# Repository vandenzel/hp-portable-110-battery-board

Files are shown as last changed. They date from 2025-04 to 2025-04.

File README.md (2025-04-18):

# HP Portable 110 Battery Board

A replacement board to stick onto the battery pack of a HP Portable 110 computer. But with some SMD parts. Also the 3 pin header should be a locking/latching part instead of "just" a pin header.

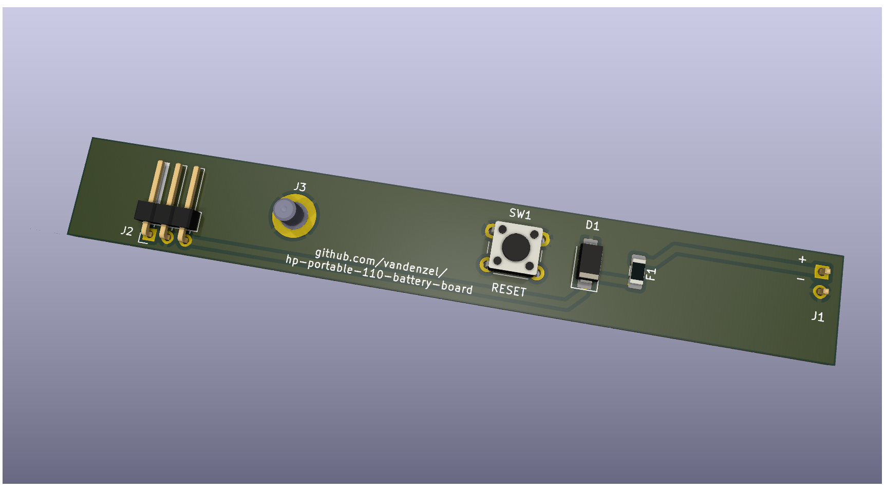
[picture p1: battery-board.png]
PCB render

I didn't have a 3D image for the F1 fuse, or the J3 stud.

## Parts list

On PCB

| Part | Description | Notes |
| ---- | --- | --- |
| D1 | 1N4001 | this should be a D_SMA package |
| F1 | 0.5A | [Mouser](https://mou.sr/42zEMhM) |
| J1 | header 1x2 2.54mm pitch | pinheader, or JST-XH, or wires soldered directly to PCB |
| J2 | header 1x3 2.54mm pitch | plain pinheader or something compatible with the locking connector |
| J3 | screw terminal | Press-fit M3 stud 6mm long ([PEM KFH-M3-6ET at Mouser](https://mou.sr/3RKMalD)) |
| SW1  | Reset switch | Tact switch |

External to PCB

| Part | Description | Notes |
| ---- | --- | --- |
| BT'1 | 6V 2.5Ah Lead Acid battery | i.e. LP 6-2.8 VRLA AGM Battery |
| J'1  | 1x02 2.54 pitch (female) | could be omitted and wires soldered directly to board |

The battery usually has spade connectors, and the amperage is not really high, so basically any wire with a spade (a.k.a AMP) connector can be used. To connect it to the circuit board you can use a pinheader (like in the image), or a (2.54mm pitch) JST-XH connector, or just solder the wire to the respective holes.

If all goes well, the circuit board can be stuck to the battery using a piece of double sided, foam core sticky tape. Foam core to allow for the through-hole pins. Before sticking it on, check the fit in the battery compartment of the Portable 110.

## Dependencies:

- KiCad (obviously), version 8.0 or later.
- The [Fabrication Toolkit](https://github.com/bennymeg/Fabrication-Toolkit) plugin for KiCad.

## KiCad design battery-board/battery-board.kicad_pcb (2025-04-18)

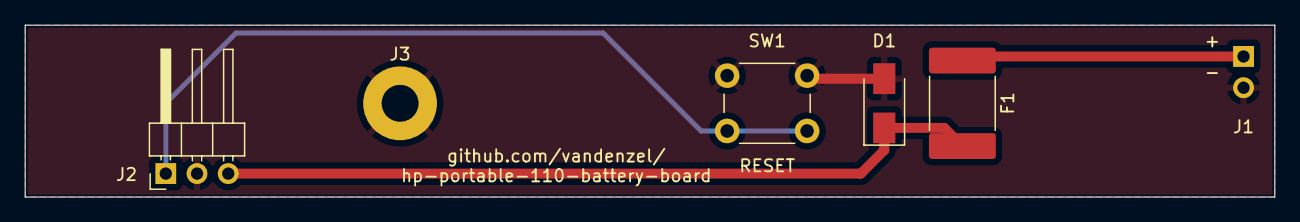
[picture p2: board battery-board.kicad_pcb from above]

Board: 2 copper layers, 101.6 x 14.0 mm, 6 parts (1 on the bottom side), 4 nets.

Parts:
D1: 1N4001; D_SMA
F1: 0.5A; Fuse_2920_7451Metric_Pad2.10x5.45mm_HandSolder
J1: Conn_01x02_Male; PinHeader_1x02_P2.54mm_Vertical
J2: Conn_01x03; PinHeader_1x03_P2.54mm_Horizontal
J3: Screw_Terminal_01x01; M3x6 Mounting stud pressfit
SW1: RESET; SW_PUSH_6mm

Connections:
/GND: D1.2 (A), J1.2, J2.2, J3.1, SW1.1
/VBB: F1.1, J1.1
/VCC: D1.1 (K), F1.2, J2.3
/~RESET: J2.1, SW1.2
